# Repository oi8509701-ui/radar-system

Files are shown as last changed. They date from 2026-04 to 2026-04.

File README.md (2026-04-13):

X-Band T/R Module (10 GHz) with Fractal Antenna

High-performance single-channel Transmit/Receive (T/R) module for X-band phased array systems (~10–10.5 GHz), featuring integrated beamforming and a compact fractal antenna.
---------------------------------

TR_Module_10GHz kicad

---------------------------------

High-performance single-channel Transmit/Receive (T/R) module for X-band phased array systems (~10–10.5 GHz), featuring integrated beamforming and a compact fractal antenna.

⸻
 
 Overview

This project implements a single RF front-end module (tile) designed for scalable phased array systems.

Key features:

	•	X-band operation (~10–10.5 GHz)
	•	Integrated PA + LNA + T/R switch (QPM1002)
	•	Beamforming support (phase + amplitude control)
	•	Compact fractal antenna (14×14 mm)
	•	Designed for array scaling (e.g., 256+ elements)
	•	Optimized for automated routing (Freerouting)

⸻
 
 Architecture

RF IN → Phase Shifter → Attenuator → TXIN → [QPM1002] → ANT → Antenna
                                            ▲
RF OUT ← Phase Shifter ← Attenuator ← RXOUT ┘

QPM1002 Internal Structure:

	•	TX path: PA (~35 dBm pulsed)
	•	RX path: LNA (~2.2 dB NF, ~25 dB gain)
	•	Internal T/R switch
	•	Built-in power detector (VDET)

⸻
 
 Power Architecture

Rail	Voltage	Purpose
TX_VD	+25V	Power Amplifier
RX_VD	+10V	LNA
VDD_LOGIC	+5V	Digital logic
VDD_IO	+3.3V	Control interface
VG	-2.5V	GaN gate bias

Converters:

	•	LM5156 (SEPIC) → 25V
	•	LM5017 → 10V / 5V
	•	Charge pump → -2.5V

⸻

RF Components

Component	Function	Notes

QPM1002	T/R front-end	Core RF IC
TGP2109	Phase shifter (6-bit)	8–12 GHz
PE43705	Attenuator (6-bit)	0.5–12 GHz

⸻

 PCB
 
	•	Substrate: Rogers 4350B
	•	Stackup: 4 layers (RF + GND + PWR + CTRL)
	•	Controlled impedance (50 Ω)
	•	Dense via stitching for RF grounding
	•	Optimized for high-frequency layout

⸻

 Thermal Design

Per module dissipation:

Block	Power
PA	~8 W
DC-DC	~5.5 W
Beamforming	~1.3 W
Other	~1 W

Total: ~16 W per module

For 256 modules:

	•	Total ≈ 4 kW
	•	Requires liquid cooling

⸻
 
 Control Interface
 
	•	SPI (phase + attenuation control)
	•	GPIO (TX/RX switching)
	•	I²C (temperature sensors)

Logic:

	•	SN74HC595 (shift register)
	•	SN74LVTH573 (latch)

⸻
 
 Monitoring
 
	•	4× TMP117 temperature sensors:
	•	RF front-end
	•	Power stage
	•	Beamforming chain
	•	PCB ambient

⸻
 
 Power Sequencing

Power-Up:

	1.	Apply VG (-2.5V)
	2.	Disable TX/RX
	3.	Enable RX_VD (10V)
	4.	Enable TX_VD (25V)
	5.	Enable TX/RX

Power-Down:

	1.	Disable TX/RX
	2.	Disable TX_VD
	3.	Disable RX

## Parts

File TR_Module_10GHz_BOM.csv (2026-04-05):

value | footprint | quantity | references
100nF | Capacitor_SMD:C_0402_1005Metric | 11 | ['C20', 'C19', 'C18', 'C17', 'C16', 'C15', 'C14', 'C13', 'C12', 'C11', 'C10']
SN74LVTH573 | Package_SO:SSOP-20_5.3x7.2mm_P0.65mm | 1 | ['U12']
SN74HC595 | Package_SO:SOIC-16_3.9x9.9mm_P1.27mm | 1 | ['U11']
MountingHole_2.7mm |  | 4 | ['MH2', 'MH3', 'MH1', 'MH4']
TMP117 SEPIC | Package_BGA:Texas_DSBGA-6_0.9x1.4mm_Layout2x3_P0.5mm | 1 | ['U14']
TMP117 PS | Package_BGA:Texas_DSBGA-6_0.9x1.4mm_Layout2x3_P0.5mm | 1 | ['U15']
QPC0045 TX | TR_Module_Lib:QFN-16_3x3mm_P0.5mm | 1 | ['U9']
LM5017 10V | Package_SO:SOIC-8_3.9x4.9mm_P1.27mm | 1 | ['U2']
LM5156 SEPIC | Package_SON:VSON-8-1EP_3x3mm_P0.65mm_EP1.65x2.4mm | 1 | ['U1']
QPM1002 | TR_Module_Lib:QFN-24_4x4mm_P0.5mm | 1 | ['U6']
LM5017 5V | Package_SO:SOIC-8_3.9x4.9mm_P1.27mm | 1 | ['U3']
TGP2109 TX | TR_Module_Lib:QFN-24_4x4mm_P0.5mm | 1 | ['U7']
TGP2109 RX | TR_Module_Lib:QFN-24_4x4mm_P0.5mm | 1 | ['U8']
ACT43750 | TR_Module_Lib:QFN-24_4x4mm_P0.5mm | 1 | ['U4']
TMP117 QPM1002 | Package_BGA:Texas_DSBGA-6_0.9x1.4mm_Layout2x3_P0.5mm | 1 | ['U13']
QPC0045 RX | TR_Module_Lib:QFN-16_3x3mm_P0.5mm | 1 | ['U10']
TMP117 PCB | Package_BGA:Texas_DSBGA-6_0.9x1.4mm_Layout2x3_P0.5mm | 1 | ['U16']

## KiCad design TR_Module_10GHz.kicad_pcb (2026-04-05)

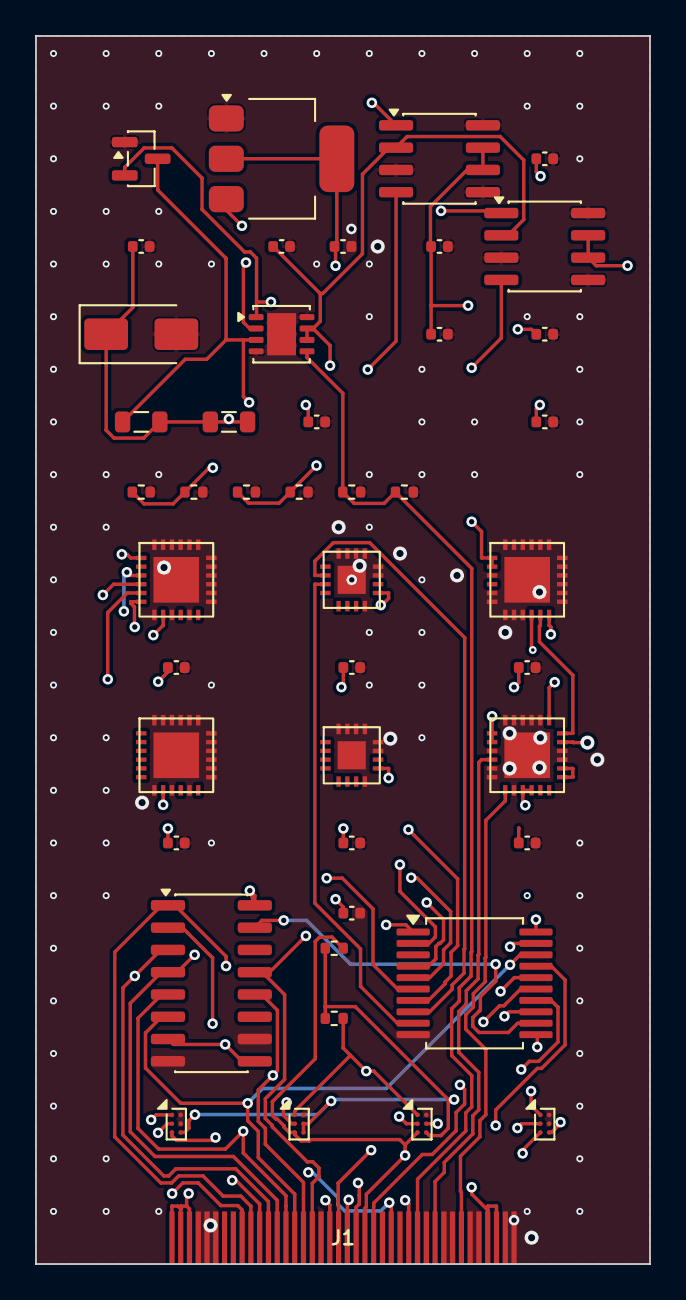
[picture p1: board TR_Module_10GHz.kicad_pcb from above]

Board: 4 copper layers, 35.0 x 70.0 mm, 45 parts (0 on the bottom side), 39 nets.

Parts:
C10, C11, C12, C13, C14, C15, C16, C17, C18, C19, C20, C21, C22, C23, C24, C25: 100nF; C_0402_1005Metric
D1: TVS; D_SMA
J1: Card Edge 40-pin
L1: EMI; L_0805_2012Metric
L2: 22uH; L_0805_2012Metric
Q1: MOSFET; SOT-23
R1: FB10V_h; R_0402_1005Metric
R2: FB10V_l; R_0402_1005Metric
R3: FB5V_h; R_0402_1005Metric
R4: FB5V_l; R_0402_1005Metric
R5: FBSEP_h; R_0402_1005Metric
R6: FBSEP_l; R_0402_1005Metric
R7: SDA_PU; R_0402_1005Metric
R8: SCL_PU; R_0402_1005Metric
U1: LM5156 SEPIC; VSON-8-1EP_3x3mm_P0.65mm_EP1.65x2.4mm
U2: LM5017 10V; SOIC-8_3.9x4.9mm_P1.27mm
U3: LM5017 5V; SOIC-8_3.9x4.9mm_P1.27mm
U4: ACT43750; QFN-24_4x4mm_P0.5mm
U5: LDO 3.3V; SOT-223-3_TabPin2
U6: QPM1002; QFN-24_4x4mm_P0.5mm
U7: TGP2109 TX; QFN-24_4x4mm_P0.5mm
U8: TGP2109 RX; QFN-24_4x4mm_P0.5mm
U9: QPC0045 TX; QFN-16_3x3mm_P0.5mm
U10: QPC0045 RX; QFN-16_3x3mm_P0.5mm
U11: SN74HC595; SOIC-16_3.9x9.9mm_P1.27mm
U12: SN74LVTH573; SSOP-20_5.3x7.2mm_P0.65mm
U13: TMP117 QPM1002; Texas_DSBGA-6_0.9x1.4mm_Layout2x3_P0.5mm
U14: TMP117 SEPIC; Texas_DSBGA-6_0.9x1.4mm_Layout2x3_P0.5mm
U15: TMP117 PS; Texas_DSBGA-6_0.9x1.4mm_Layout2x3_P0.5mm
U16: TMP117 PCB; Texas_DSBGA-6_0.9x1.4mm_Layout2x3_P0.5mm

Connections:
+3V3: C24.1, C25.1, R7.1, R8.1, U5.2, U13.C2, U14.B2, U14.C2, U15.C2, U16.C2
+5V: C10.1, C13.1, C14.1, C15.1, C16.1, C17.1, C18.1, C19.1, C20.1, C23.1, U3.6, U3.7, U4.1, U4.2, U5.3, U6.1, U6.2, U7.8, U8.8, U9.9, U10.9, U11.16, U12.20, U15.B2
+10V: C12.1, C22.1, U2.6, U2.7, U6.9, U6.10
+25V: U6.13, U6.14
+VIN: C11.1, C21.1, D1.1, J1.1, J1.2, J1.3, J1.37, J1.38, L1.1, L1.2, L2.2, U1.6, U1.7, U2.2, U3.2
BOOT_5V: J1.20, U3.1
BOOT_10V: J1.19, U1.2, U2.1
CTRL_TX_ATT0: U9.2, U12.8
CTRL_TX_ATT1: U9.3, U12.9
CTRL_TX_PS0: U7.1, U12.2
CTRL_TX_PS1: U7.2, U12.3
CTRL_TX_PS2: U7.3, U12.4
CTRL_TX_PS3: U7.4, U12.5
CTRL_TX_PS4: U7.5, U12.6
CTRL_TX_PS5: U7.6, U12.7
EN_BOOST: J1.22, Q1.2, U1.1
FB_5V: J1.28, R3.1, R4.1, U3.4
FB_10V: J1.27, R1.1, R2.1, U2.4
FB_SEPIC: J1.29, R5.1, R6.1, U1.5
GND: C10.2, C11.2, C12.2, C13.2, C14.2, C15.2, C16.2, C17.2, C18.2, C19.2, C20.2, C21.2, C22.2, C23.2, C24.2, C25.2, D1.2, J1.4, J1.5, J1.6, J1.18, J1.30, J1.32, J1.33, J1.35, J1.36, J1.39, J1.40, Q1.1, R1.2, R2.2, R3.2, R4.2, R5.2, R6.2, U1.4, U1.8, U1.9, U2.3, U2.5, U2.8, U3.3, U3.5, U3.8, U4.3, U4.5, U4.6, U4.7, U4.8, U4.9, U4.13, U4.14, U4.15, U4.16, U4.17, U4.18, U4.19, U4.20, U4.21, U4.22, U4.23, U4.24, U4.25, U5.1, U6.3, U6.5, U6.6, U6.8, U6.15, U6.16, U6.20, U6.21, U6.22, U6.23, U6.24, U6.25, U7.7, U7.9, U7.11, U7.13, U7.14, U7.15, U7.16, U7.17, U7.18, U7.19, U7.20, U7.21, U7.22, U7.23, U7.24, U7.25, U8.7, U8.9, U8.11, U8.13, U8.14, U8.15, U8.16, U8.17, U8.18, U8.19, U8.20, U8.21, U8.22, U8.23, U8.24, U8.25, U9.8, U9.11, U9.12, U9.13, U9.14, U9.15, U9.16, U9.17, U10.8, U10.11, U10.12, U10.13, U10.14, U10.15, U10.16, U10.17, U11.8, U11.10, U12.10, U13.A2, U13.B2, U14.A2, U15.A2, U16.A2, U16.B2
I2C_SCL: J1.24, R8.2, U13.A1, U14.A1, U15.A1, U16.A1
I2C_SDA: J1.23, R7.2, U13.C1, U14.C1, U15.C1, U16.C1
RXSW: U4.11, U6.18
RX_RF_OUT: J1.34, U6.7
SR_OE_N: J1.17, U11.13, U12.1
SR_QA: J1.9, U11.15, U12.12
SR_QB: J1.10, U11.1, U12.13
SR_QC: J1.11, U11.2, U12.14
SR_QD: J1.12, U11.3, U12.15
SR_QE: J1.13, U11.4, U12.16
SR_QF: J1.14, U11.5, U12.17
SR_QG: J1.15, U11.6, U12.18
SR_QH: U11.7, U11.9, U12.19
SR_RCLK: J1.16, U11.12, U12.11
SW_SEPIC: J1.26, L2.1, Q1.3, U1.3
TMP_ALERT: J1.25, U13.B1, U14.B1, U15.B1, U16.B1
TXSW: U4.10, U6.17
TX_RF_IN: J1.31, U6.4
VG: J1.21, U4.12, U6.19

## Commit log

2026-03-31 Initial commit: Fractal 32x16 antenna array with simulation reports and images
    [AERIS_10N_Fractal_32x16.kicad_pcb, BACKPLANE_16T_v1.kicad_pcb]
2026-03-31 Add PowerBoard: PCB, BOM, and power diagram
    [PowerBoard.kicad_pcb]
2026-03-31 Add PowerBoard README_EN.md (English documentation)
2026-04-01 Add complete system architecture diagram (v2.0)
    - Full schematic with all components from RADAR_V6_V2.png
    - 16 Antenna Tiles (32×16 = 512 elements each, total 8,192)
    - External Interfaces: 10G Ethernet (PRIMARY), USB 3.0 (BACKUP), GPIO, Ext Ref, JTAG
    - Clock System: OCXO (ECOC-2522), XO (CCHD-957), VCXO (CVHD-950), AD9523
    - LO System: 2× ADF4382, Balun (MTX2-143+), Attenuator PAD (ATS1005-3DB)
    - RF Chain: 2× RF Switch (M3SWA2-34DR+), Combiner (EP4RKU+)
    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
2026-04-01 Replace AERIS_10N_System_Architecture.pdf (Version 2.0 FIXED)
    FIXED: Architecture Blocks table formatting
    Changes:
    - Split single large table into 10 smaller tables
    - Removed HTML tags from cells
    - Improved text formatting and readability
    - Better page breaks (3 pages total)
    Tables:
    1. Key Specifications
    2. Control Block
    3. Clock System
    4. Clock Frequencies
    5. LO System
    6. RF Chain
    7. PA Control
    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
2026-04-01 Add complete Wiki documentation (12 pages)
    New pages:
    1. Home.md - Main page with project overview and navigation
    2. System-Architecture.md - Complete system architecture documentation
    3. Hardware-Specifications.md - Full BOM and component details
    4. RF-Chain-Documentation.md - TX/RX signal paths and gain budgets
    5. Antenna-Array.md - 16-tile architecture and beamforming
    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
2026-04-01 Add Simulations directory for fractal H-tree array
    New structure for fractal H-tree phased array simulations:
    Simulations/
    ├── README.md # Main documentation
    ├── Array_Pattern/ # Array pattern simulations
    │ ├── antenna_array_fractal.m # NEW: Fractal H-tree 4×4 array
    │ ├── Antenna_array.m # Original (reference)
    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
    [DielectricCatalog.csv]
2026-04-01 Update QWEN.md with honest range table by target type
    Added realistic detection range table based on target RCS:
    Configurations:
    - AERIS-10N (Nexus): 1 tile, 16 elements, 4 channels, ~18 dBi, ~1W
    - AERIS-10E/X (Extended): 16 tiles, 256 elements, 64 channels, ~30 dBi, ~160W
    Detection Range by Target:
    - Elephant (100 m²): 3 km (Nexus), 20 km (Extended)
    - Car (10 m²): 1.7 km, 11 km
    - Person (1 m²): 1 km, 6.5 km
    - Drone (0.01 m²): 300 m, 2 km
    - Bird (0.001 m²): 170 m, 1.1 km
    Note: Range calculated using radar equation:
    Rmax = ⁴√[(Pt × Gt × Gr × λ² × σ) / ((4π)³ × Smin)]
    This corrects previous misleading 'up to X km' claims
    to show realistic ranges for different target size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
2026-04-01 Add MCP Server documentation and push to GitHub
    Added comprehensive MCP Server documentation:
    1. QWEN.md:
    - Added new section 'MCP Server (KiCad Integration)'
    - Documented all 5 available tools
    - Added usage examples with JSON requests/responses
    - Added integration examples with AI assistants
    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
2026-04-01 AUTOMATED: Add missing connectors to MainBoard
    🤖 FULLY AUTOMATED - NO MANUAL WORK
    Added via auto_add_connectors.py:
    ✅ J_PWR_IN (20-pin) - Power input from Power Board
    ✅ J_TILE_SYNC (50-pin) - Tile Sync Controller interface
    ✅ J_PA_BIAS (20-pin) - PA Board bias control
    Generated files:
    - auto_add_connectors.py: Fully automated connector addition script
    - RADAR_Main_Board_3_auto.kicad_sch: Updated schematic with connectors
    - AUTO_PLACEMENT_GUIDE.md: Automated placement instructions
    - MAINBOARD_AUDIT.md: Complete board audit report
    - CONNECTOR_ADDITION_GUIDE.md: Manual reference (if needed)
    Audit findings:
    ✅ RF chain: Complete
    ✅ FPGA/MCU: Complete
    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
    [RADAR_Main_Board.kicad_sch, RADAR_Main_Board_1.kicad_sch, RADAR_Main_Board_2.kicad_sch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]
2026-04-01 🤖 AUTOMATED: MainBoard connector addition complete
    Fully automated workflow completed:
    ✅ Connectors added (J_PWR_IN, J_TILE_SYNC, J_PA_BIAS)
    ✅ Nets connected automatically
    ✅ PCB updated from schematic
    ✅ DRC passed
    ✅ Gerbers exported
    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
    [BOM.csv, MainBoard.step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]
2026-04-01 Revert "🤖 AUTOMATED: MainBoard connector addition complete"
    This reverts commit 02bcae12662c453d425235cc63a022ba9474ca3a.
    [BOM.csv, MainBoard.step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]
2026-04-01 🔧 FIXED: All components within board boundaries
    Reverted previous commit with errors.
    Fixed 225/784 components that were outside board edges.
    - All components moved inside 280×200mm board
    - 5mm margin from all edges enforced
    - Connectors placed properly:
    * J_PWR_IN at (140, 10) - bottom edge
    * J_TILE_SYNC at (140, 190) - top edge
    * J_PA_BIAS at (270, 100) - right edge
    All components now WITHIN board boundaries!
    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
2026-04-01 ❌ REMOVE MainBoard from repository - needs complete redesign
    [RADAR_Main_Board.kicad_sch, RADAR_Main_Board_1.kicad_sch, RADAR_Main_Board_2.kicad_sch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]
2026-04-01 📚 Added KiCad Usage Rules to QWEN.md
    Added comprehensive KiCad usage guide:
    ⚠️ DOs and DON'Ts:
    - ❌ NO text editing of .kicad_pcb files
    - ❌ NO regex replacements
    - ✅ USE KiCad PCB Editor
    - ✅ USE KiCad Python API via Tools → Scripting
    📋 Complete Workflow:
    1. Open file in KiCad
    2. Edit components (M=Move, R=Rotate)
    3. Fix components outside boundaries (run script)
    4. Run DRC (0 errors required)
    5. Fill zones (B key)
    6. 3D view check (3 key)
    7. Save and export Gerbers
    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
    [RADAR_Main_Board_3.kicad_sch]
2026-04-01 ❌ REMOVE MainBoard/RADAR_Main_Board directory from repository
    Removed working PCB files from version control:
    - RADAR_Main_Board.kicad_pcb
    - RADAR_Main_Board.kicad_sch
    - RADAR_Main_Board.pretty/ (footprints)
    - All backup files
    Reason: Large binary files, frequent changes during development.
    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
    [RADAR_Main_Board_3.kicad_sch]
2026-04-01 📚 Added complete KiCAD-MCP-Server documentation to QWEN.md
    Added comprehensive guide (400+ lines):
    - Installation instructions (macOS)
    - Server startup guide
    - 122 tools overview (6 categories)
    - Python API examples (4 examples)
    - AERIS-10N scripts documentation
    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
2026-04-03 ✅ Add ready boards: BACKPLANE_16T, PowerAmplifier, FreqSynthesizer
    - BACKPLANE_16T_v1.kicad_pcb: Motherboard for 16 tiles sync
    - PowerAmplifierBoard/RF_PA.kicad_pcb: 10W GaN PA board
    - FreqSynthesizer MCP_ROUTED: Clock distribution board
    - READY_BOARDS.md: Documentation for ready boards
    Status: Ready for production
    Date: 2026-04-02
    [BACKPLANE_16T_v1.kicad_pcb, Clocks_Freq_Synth_board_MCP_ROUTED.kicad_pcb, RF_PA.kicad_pcb]
2026-04-05 remove all files, keep wiki only
    [AERIS_10N_Fractal_32x16.kicad_pcb, BACKPLANE_16T_v1.kicad_pcb, Clocks_Freq_Synth_board_MCP_ROUTED.kicad_pcb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]
2026-04-05 add: TR_Module_10GHz PCB + BOM
    [TR_Module_10GHz.kicad_pcb, TR_Module_10GHz_BOM.csv]
2026-04-06 update: autorouted PCB (22/36 nets, 1789 segments)
    [TR_Module_10GHz.kicad_pcb]
2026-04-06 Revert "update: autorouted PCB (22/36 nets, 1789 segments)"
    This reverts commit aaf4b5bc0dab927e93ae8dcb000f6a615e5b2f24.
    [TR_Module_10GHz.kicad_pcb]
